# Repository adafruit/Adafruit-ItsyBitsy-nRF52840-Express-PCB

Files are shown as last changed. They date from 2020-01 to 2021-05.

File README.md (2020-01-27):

## Adafruit ItsyBitsy nRF52840 Express PCB

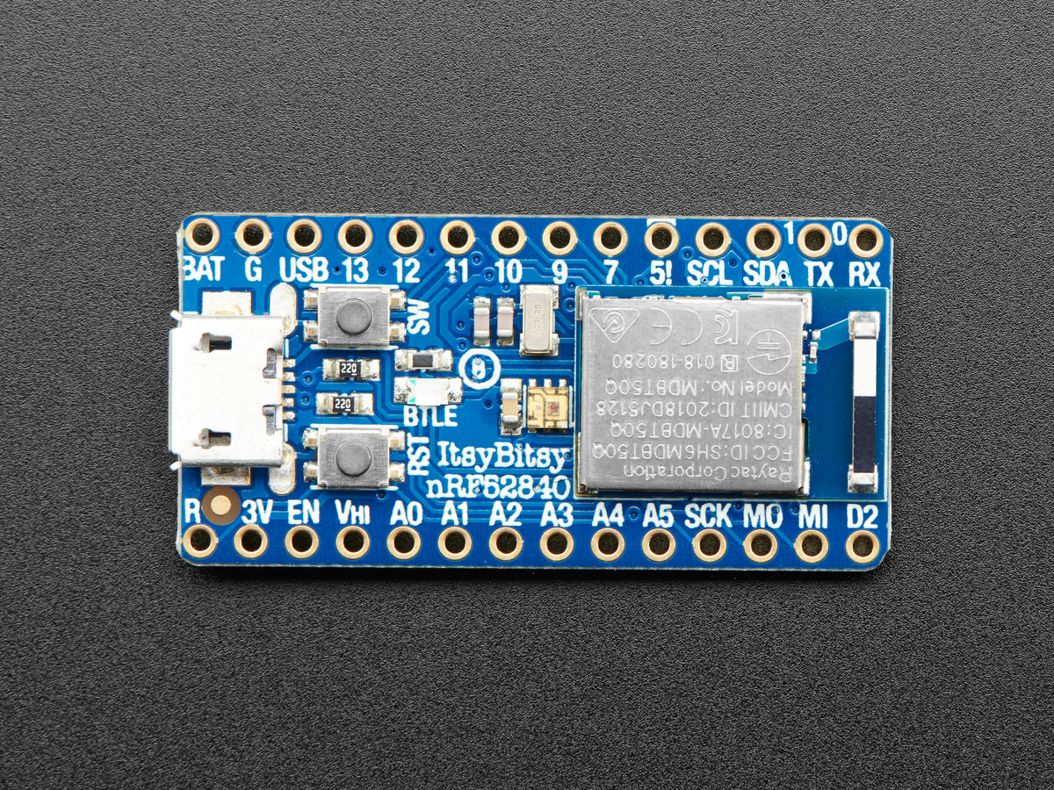
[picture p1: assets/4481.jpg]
<a href="http://www.adafruit.com/products/4481"><br/>
Click here to purchase one from the Adafruit shop</a>

PCB files for the Adafruit ItsyBitsy nRF52840 Express. 

Format is EagleCAD schematic and board layout
* https://www.adafruit.com/product/4481

### Description

What's smaller than a Feather but larger than a Trinket? It's an Adafruit ItsyBitsy nRF52840 Express featuring the Nordic nRF52840 Bluetooth LE processor! Teensy & powerful, with an fast nRF52840 Cortex M4 processor running at 64 MHz and 1 MB of FLASH - this microcontroller board is perfect when you want something very compact, with a heap-load of memory and Bluetooth LE support This Itsy is your best option for tiny wireless connectivity - it can act as both a BLE central and peripheral, with support in both Arduino and CircuitPython

ItsyBitsy nRF52840 Express is only 1.4" long by 0.7" wide, but has 6 power pins, 21 digital GPIO pins (6 of which can be analog in). It's the same chip as the Feather nRF52840 but really really small. So it's great for thse really compact builds. It even comes with 2MB of QSPI Flash built in, for data logging, file storage, or CircuitPython code.

The most exciting part of the ItsyBitsy is that while we ship it with an Arduino IDE compatible demo, you can also install CircuitPython on board with only a few clicks. When you plug it in, it will show up as a very small disk drive with code.py on it. Edit code.py with your favorite text editor to build your wireless-enabled project using Python, the most popular programming language. No installs, IDE or compiler needed, so you can use it on any computer, even ChromeBooks or computers you can't install software on. When you're done, unplug the Itsy' and your code will go with you.

Here are some of the updates you can look forward to when using ItsyBitsy nRF52:

* Same size, form-factor as the remaining ItsyBitsy mainboards - with a similar but not identical pinout (there's no pins at the end of the board like most other Itsy's due to the radio antenna being there.
* Floating point support with Cortex M4 DSP instructions
* 32-bit, 3.3V logic and power with power/enable pin
* 1024 KB flash, 256 KB RAM
* 2 MB QSPI FLASH chip for storing files and CircuitPython code storage.
* Native Open Source USB stack - pre-programmed with UF2 bootloader
* Bluetooth Low Energy compatible 2.4GHz radio (Details available in the nRF52840 product specification)
* FCC / IC / TELEC certified module
* Up to +8dBm output power
* 21 GPIO, 6 x 12-bit ADC pins, up to 12 PWM outputs (3 PWM modules with 4 outputs each)
* Red LED for general purpose blinking, mini DotStar RGB LED for colorful feedback
* 1 x Special Vhigh output pin gives you the higher voltage from VBAT or VUSB, for driving NeoPixels, servos, and other 5V-logic devices. Digital 5 level-shifted output for high-voltage logic level output.
* Native USB supported by every OS - can be used in Arduino or CircuitPython as USB serial console, Keyboard/Mouse HID, even a little disk drive for storing Python scripts.
* Can be used with Arduino IDE or CircuitPython
* Comes pre-loaded with the UF2 bootloader, which looks like a USB storage key. Simply drag firmware on to program, no special tools or drivers needed! It can be used to load up CircuitPython or Arduino IDE

Each order comes with one assembled and tested ItsyBitsy nRF52840, with headers that can be soldered in for use with a breadboard.

So what are you waiting for? Pick up a ItsyBitsy nRF today and be amazed at how easy and fast it is to get started with the teensiest  Bluetooth dev board we have.

### License

Adafruit invests time and resources providing this open source design, please support Adafruit and open-source hardware by purchasing products from [Adafruit](https://www.adafruit.com)!

Designed by Limor Fried/Ladyada for Adafruit Industries.

Creative Commons Attribution/Share-Alike, all text above must be included in any redistribution. 
See license.txt for additional details.

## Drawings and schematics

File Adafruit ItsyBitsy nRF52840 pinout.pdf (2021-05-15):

# Adafruit ItsyBitsy nRF52840

## https://www.adafruit.com/product/4481

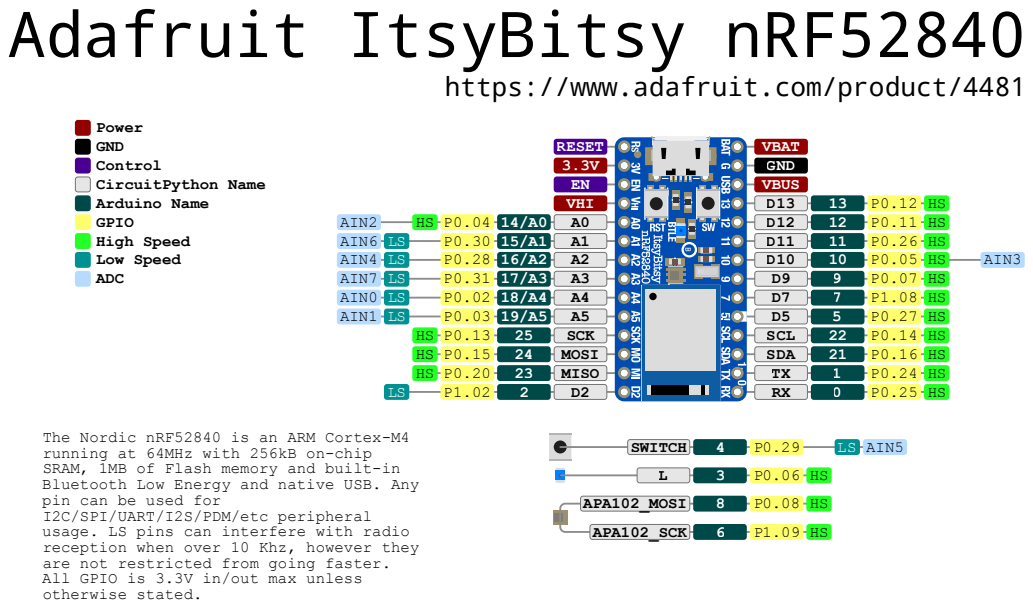
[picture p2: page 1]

The Nordic nRF52840 is an ARM Cortex-M4
running at 64MHz with 256kB on-chip
SRAM, 1MB of Flash memory and built-in
Bluetooth Low Energy and native USB. Any
pin can be used for
I2C/SPI/UART/I2S/PDM/etc peripheral
usage. LS pins can interfere with radio
reception when over 10 Khz, however they
are not restricted from going faster.
All GPIO is 3.3V in/out max unless
otherwise stated.

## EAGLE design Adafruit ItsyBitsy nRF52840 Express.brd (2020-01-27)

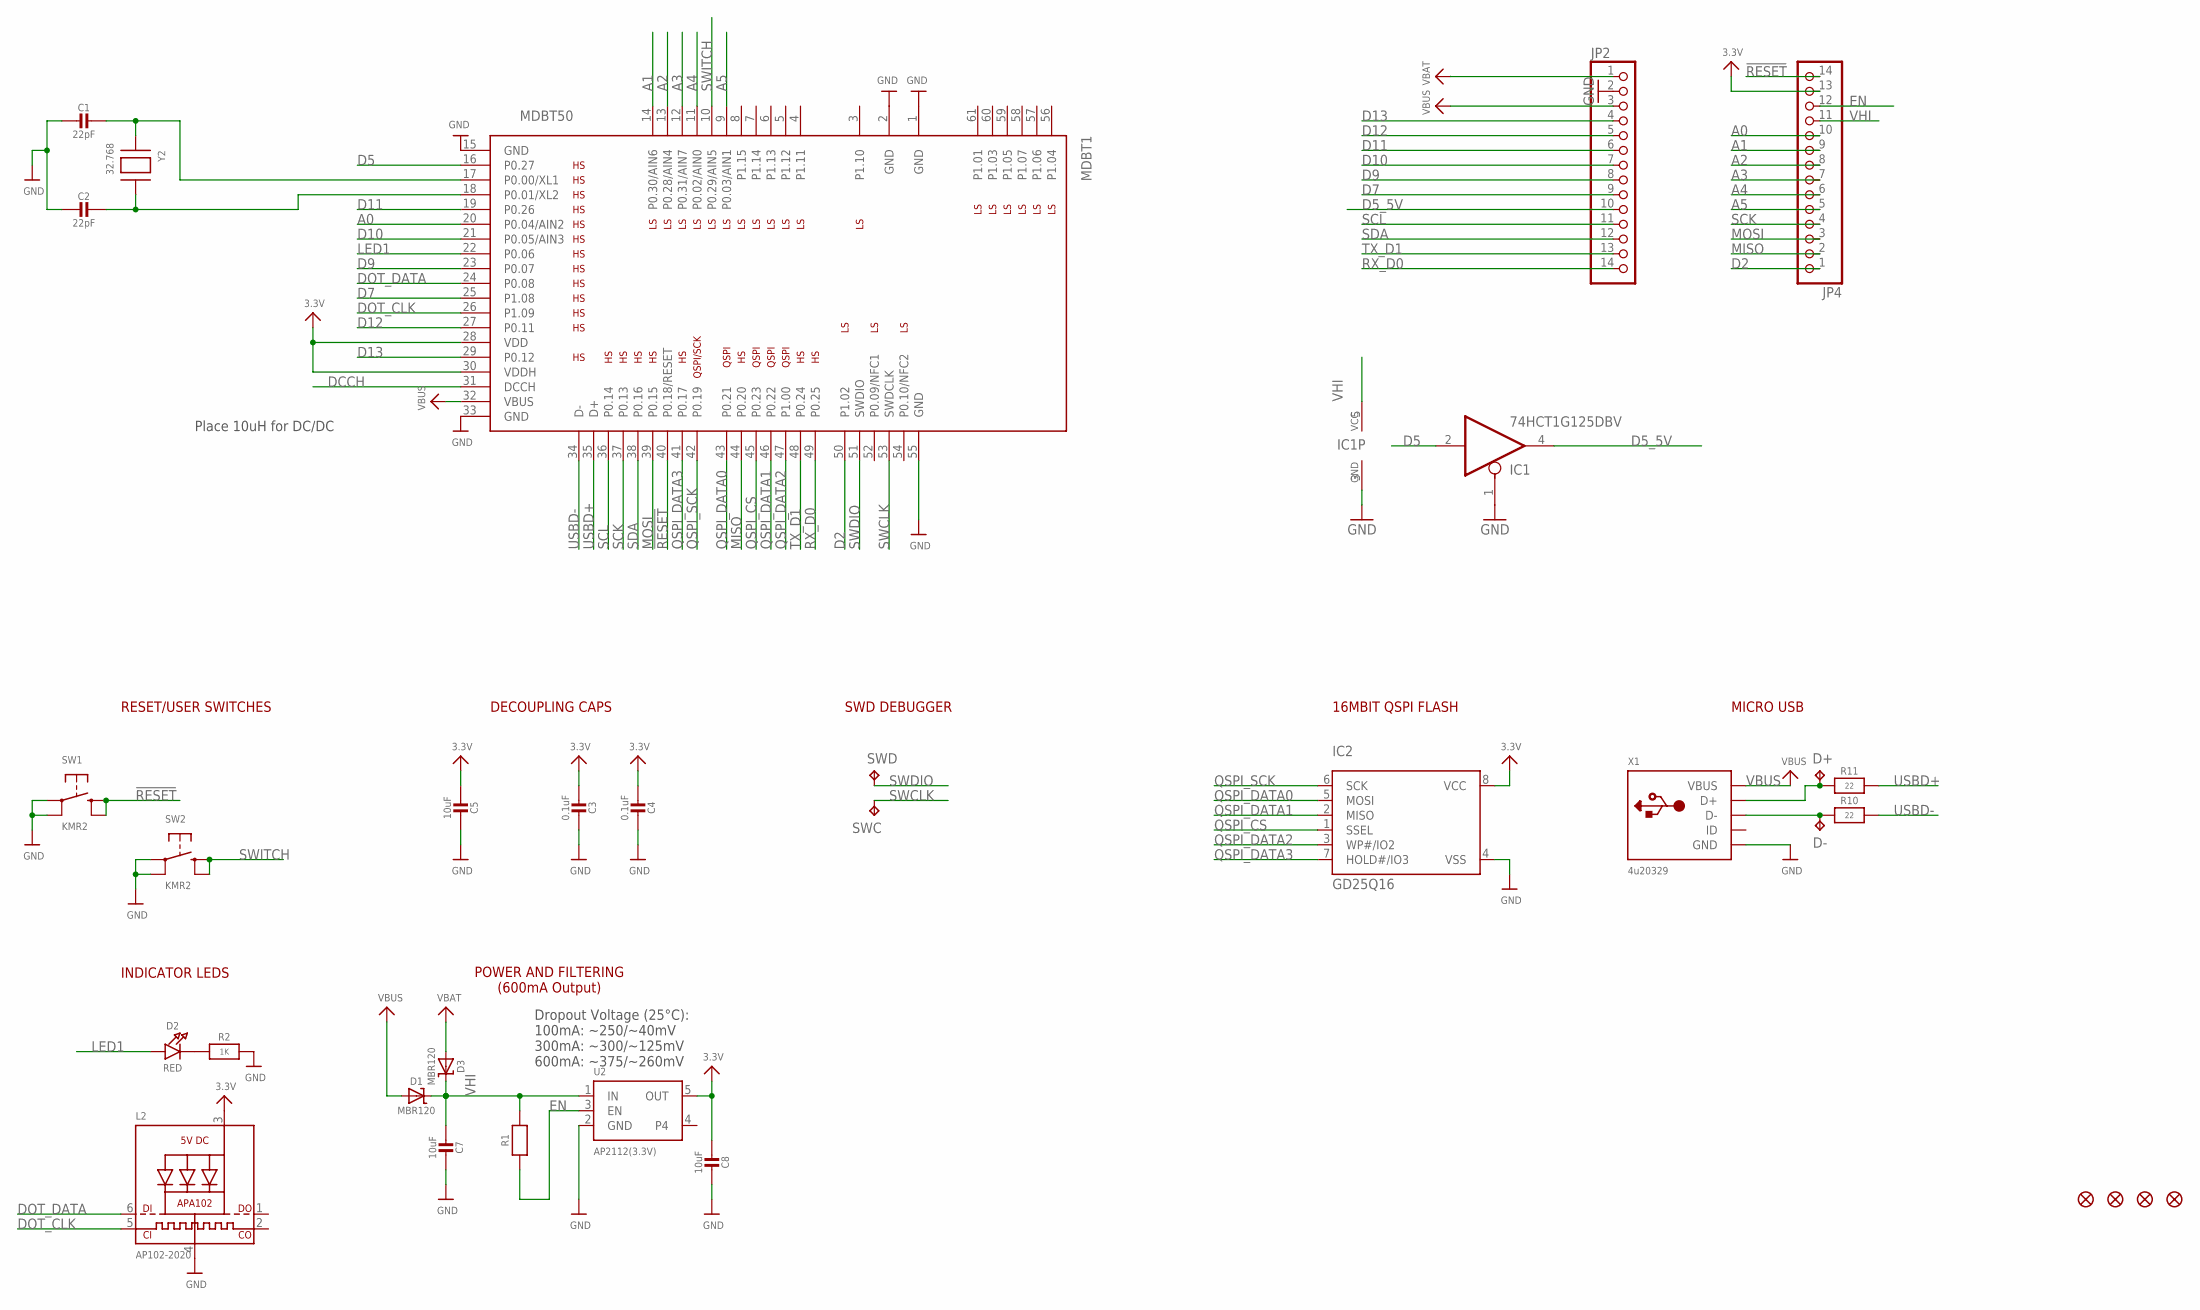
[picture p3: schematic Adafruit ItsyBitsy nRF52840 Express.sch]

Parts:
C1, C2: 22pF; _0603MP
C3, C4: 0.1uF; 0603-NO
C5, C7, C8: 10uF; 0805-NO
D1, D3: MBR120; SOD-123
D2: RED; CHIPLED_0805_NOOUTLINE
D+: TPTP10R; TP10R
D-: TPTP10R; TP10R
FID1, FID2, FID3, FID4: FIDUCIAL_1MM
IC1: 74HCT1G125DBV; SOT23-5
IC2: GD25Q16; USON8
JP2, JP4: HEADER-1X14; 1X14_ROUND70
L2: AP102-2020; APA102_2020
MDBT1: MDBT50
R1: 10K; 0603-NO
R2: 1K; 0603-NO
R10, R11: 22; 0603-NO
SW1, SW2: KMR2; BTN_KMR2_4.6X2.8
SWC: TPTP13R; TP13R
SWD: TPTP13R; TP13R
U2: AP2112(3.3V); SOT23-5
X1: 4u20329; 4UCONN_20329_V2
Y2: 32.768; XTAL3215

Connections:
3.3V: C3.2, C4.2, C5.2, C8.2, IC2.8 (VCC), JP4.13, L2.3 (VDD), MDBT1.28 (VDD), MDBT1.30 (VDDH), U2.5 (OUT)
!RESET: JP4.14, MDBT1.40 (P0.18/RESET), SW1.B (S), SW1.B' (S1)
A0: JP4.10, MDBT1.20 (P0.04/AIN2)
A1: JP4.9, MDBT1.14 (P0.30/AIN6)
A2: JP4.8, MDBT1.13 (P0.28/AIN4)
A3: JP4.7, MDBT1.12 (P0.31/AIN7)
A4: JP4.6, MDBT1.11 (P0.02/AIN0)
A5: JP4.5, MDBT1.9 (P0.03/AIN1)
D2: JP4.1, MDBT1.50 (P1.02)
D5: IC1.2 (I), MDBT1.16 (P0.27)
D5_5V: IC1.4 (O), JP2.10
D7: JP2.9, MDBT1.25 (P1.08)
D9: JP2.8, MDBT1.23 (P0.07)
D10: JP2.7, MDBT1.21 (P0.05/AIN3)
D11: JP2.6, MDBT1.19 (P0.26)
D12: JP2.5, MDBT1.27 (P0.11)
D13: JP2.4, MDBT1.29 (P0.12)
D+: D+.TP, R11.1, X1.D+
D-: D-.TP, R10.1, X1.D-
DCCH: MDBT1.31 (DCCH)
DOT_CLK: L2.5 (CKI), MDBT1.26 (P1.09)
DOT_DATA: L2.6 (DI), MDBT1.24 (P0.08)
EN: JP4.12, R1.1, U2.3 (EN)
GND: C1.2, C2.2, C3.1, C4.1, C5.1, C7.1, C8.1, IC1.1 (OE), IC1.3 (GND), IC2.4 (VSS), JP2.2, L2.4 (GND), MDBT1.1 (GND), MDBT1.2 (GND), MDBT1.15 (GND), MDBT1.33 (GND), MDBT1.55 (GND), R2.2, SW1.A, SW1.A' (P1), SW2.A, SW2.A' (P1), U2.2 (GND), X1.BASE@1 (GND), X1.BASE@2 (GND), X1.GND, X1.SPRT@1 (GND), X1.SPRT@2 (GND), X1.SPRT@3 (GND), X1.SPRT@4 (GND)
LED1: D2.A, MDBT1.22 (P0.06)
MISO: JP4.2, MDBT1.44 (P0.20)
MOSI: JP4.3, MDBT1.39 (P0.15)
unnamed: D2.C, R2.1
unnamed: C1.1, MDBT1.17 (P0.00/XL1), Y2.P$1
unnamed: C2.1, MDBT1.18 (P0.01/XL2), Y2.P$2
QSPI_CS: IC2.1 (SSEL), MDBT1.45 (P0.23)
QSPI_DATA0: IC2.5 (MOSI), MDBT1.43 (P0.21)
QSPI_DATA1: IC2.2 (MISO), MDBT1.46 (P0.22)
QSPI_DATA2: IC2.3 (WP#/IO2), MDBT1.47 (P1.00)
QSPI_DATA3: IC2.7 (HOLD#/IO3), MDBT1.41 (P0.17)
QSPI_SCK: IC2.6 (SCK), MDBT1.42 (P0.19)
RX_D0: JP2.14, MDBT1.49 (P0.25)
SCK: JP4.4, MDBT1.37 (P0.13)
SCL: JP2.11, MDBT1.36 (P0.14)
SDA: JP2.12, MDBT1.38 (P0.16)
SWCLK: MDBT1.53 (SWDCLK), SWC.TP
SWDIO: MDBT1.51 (SWDIO), SWD.TP
SWITCH: MDBT1.10 (P0.29/AIN5), SW2.B (S), SW2.B' (S1)
TX_D1: JP2.13, MDBT1.48 (P0.24)
USBD+: MDBT1.35 (D+), R11.2
USBD-: MDBT1.34 (D-), R10.2
VBAT: D3.A, JP2.1
VBUS: D1.A, JP2.3, MDBT1.32 (VBUS), X1.VBUS
VHI: C7.2, D1.C, D3.C, IC1.5 (VCC), JP4.11, R1.2, U2.1 (IN)

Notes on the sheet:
POWER AND FILTERING (600mA Output)
Dropout Voltage (25°C): 100mA: ~250/~40mV 300mA: ~300/~125mV 600mA: ~375/~260mV
INDICATOR LEDS
RESET/USER SWITCHES
DECOUPLING CAPS
SWD DEBUGGER
16MBIT QSPI FLASH
MICRO USB
Place 10uH for DC/DC

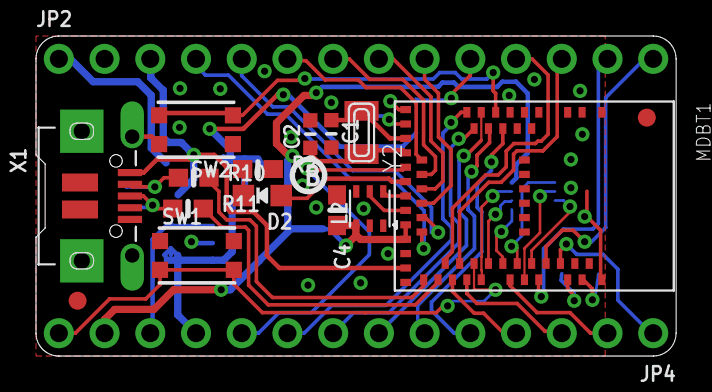
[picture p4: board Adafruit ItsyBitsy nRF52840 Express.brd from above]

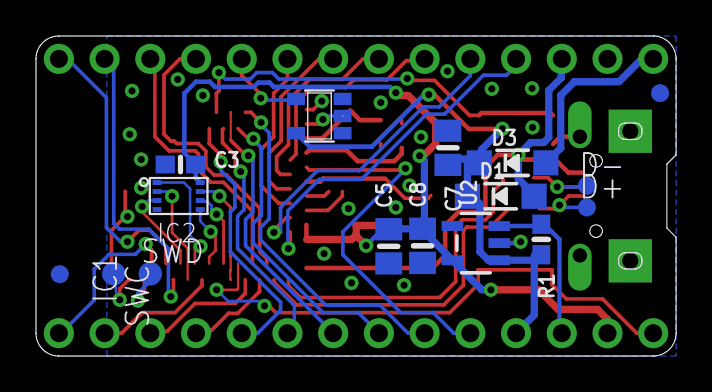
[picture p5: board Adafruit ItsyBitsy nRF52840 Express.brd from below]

Board: 2 copper layers, 35.6 x 17.8 mm, 36 parts (17 on the bottom side), 48 nets.

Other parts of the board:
U$12: ITSYNRF52840_TOP
U$14: ITSYNRF52840_BOT
U$15: PCBFEAT-REV-040

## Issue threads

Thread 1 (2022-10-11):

Add a cutable jumper to disconnect the RGB LED

Eric-FR, 2022-10-11:
The ItsyBitsy-nRF82540 board has a DotStar LED (ref. APA102-2020) with a Quiescent Current of 0,8 mA ([https://memcpy.io/apa102-led-current-usage.html](https://memcpy.io/apa102-led-current-usage.html)). At idle, this is the first power consumption of the board. The only way to bypass it is to unsolder the LED. It would be much easer if a jumper that we can cut was available to cut LED powering.

In relation with https://github.com/adafruit/Adafruit-nRF52-Bluefruit-Feather-PCB/issues/4

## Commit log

2020-01-27 Adding board files.
    [Adafruit ItsyBitsy nRF52840 Express.brd, Adafruit ItsyBitsy nRF52840 Express.sch]
2021-05-15 Add pin reference PDF

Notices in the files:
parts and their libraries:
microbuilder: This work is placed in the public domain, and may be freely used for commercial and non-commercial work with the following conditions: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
